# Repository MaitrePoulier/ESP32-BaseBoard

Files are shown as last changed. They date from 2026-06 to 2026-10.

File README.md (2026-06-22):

The goals of this BaseBoard:
* Support Bluetooth legacy for receiving audio from an external audio source
* Support 2x 18650 LiFePo4 cell that can be charged with the USB connector
* Low noise +/- 12.4V going to the mezzanine to powered Audio op-amp
* I2S port going to the mezz
* Support of the MHS 4.0 screen (ST7796S) with touch (XPT2046)
* can be placed inside an Pelican 1040 Micro Case

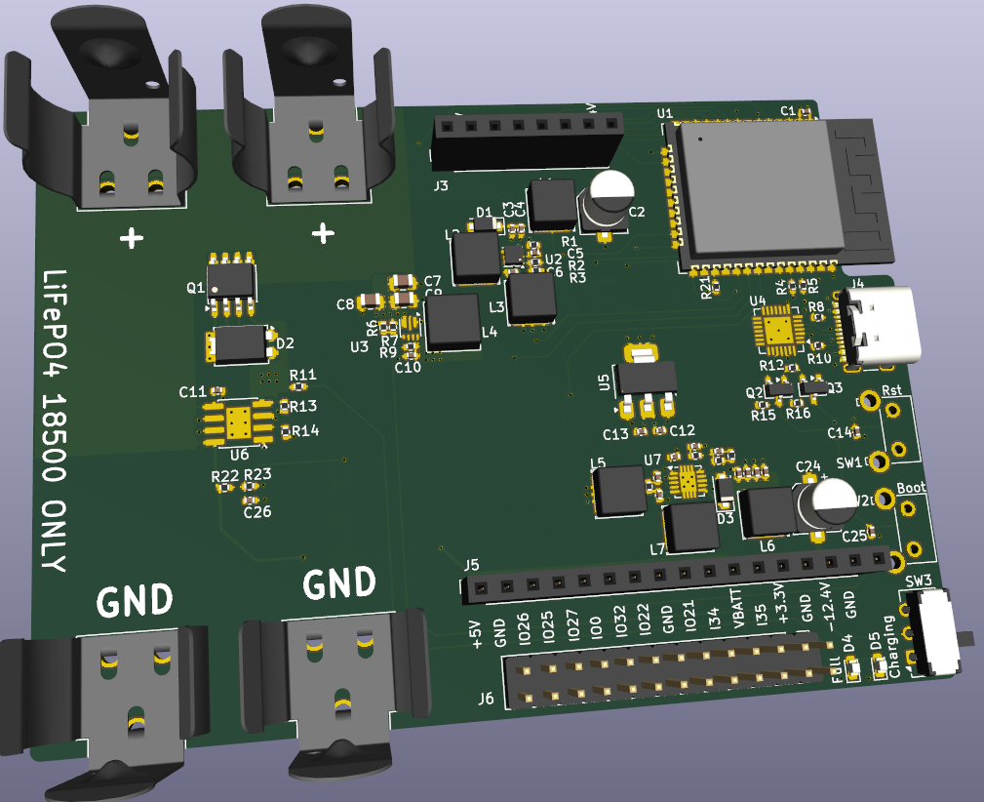
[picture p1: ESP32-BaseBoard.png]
ESP32 BaseBoard Picture


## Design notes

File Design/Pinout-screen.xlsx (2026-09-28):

 | ER-TFT043A1-1
 | Pin | Name | Type | Description
 | 1 | VLED- | Power | Backlight LED Cathode (Negative)
 | 2 | VLED+ | Power | Backlight LED Anode (Positive)
 | 3 | GND | Power | Ground
 | 4 | VDD | Power | Analog Power Supply (2.8V - 3.3V)
 | 5 | VDDIO | Power | Digital I/O Power Supply (1.65V - 3.3V)
 | 6 | RESET | Input | Global Reset Signal (Active Low)
 | 7 | CS | Input | SPI Chip Select (Active Low)
 | 8 | SCL | Input | SPI Clock Signal
 | 9 | SDA | I/O | SPI Data Input / Output
 | 10 | SDO | Output | SPI Data Output (MISO)
 | 11 | PCLK | Input | RGB Pixel Clock Signal
 | 12 | DE | Input | RGB Data Enable Signal
 | 13 | HSYNC | Input | RGB Horizontal Sync Signal
 | 14 | VSYNC | Input | RGB Vertical Sync Signal
 | 15 | D0 | Input | RGB Data Blue 0 (LSB)
 | 16 | D1 | Input | RGB Data Blue 1
 | 17 | D2 | Input | RGB Data Blue 2
 | 18 | D3 | Input | RGB Data Blue 3
 | 19 | D4 | Input | RGB Data Blue 4
 | 20 | D5 | Input | RGB Data Blue 5
 | 21 | D6 | Input | RGB Data Blue 6
 | 22 | D7 | Input | RGB Data Blue 7 (MSB)
 | 23 | D8 | Input | RGB Data Green 0 (LSB)
 | 24 | D9 | Input | RGB Data Green 1
 | 25 | D10 | Input | RGB Data Green 2
 | 26 | D11 | Input | RGB Data Green 3
 | 27 | D12 | Input | RGB Data Green 4
 | 28 | D13 | Input | RGB Data Green 5
 | 29 | D14 | Input | RGB Data Green 6
 | 30 | D15 | Input | RGB Data Green 7 (MSB)
 | 31 | D16 | Input | RGB Data Red 0 (LSB)
 | 32 | D17 | Input | RGB Data Red 1
 | 33 | D18 | Input | RGB Data Red 2
 | 34 | D19 | Input | RGB Data Red 3
 | 35 | D20 | Input | RGB Data Red 4
 | 36 | D21 | Input | RGB Data Red 5
 | 37 | D22 | Input | RGB Data Red 6
 | 38 | D23 | Input | RGB Data Red 7 (MSB)
 | 39 | GND | Power | Ground
 | 40 | NC | - | No Connection
 | 41 | NC | - | No Connection
 | 42 | NC | - | No Connection
 | 43 | NC | - | No Connection | 33
 | 44 | NC | - | No Connection
 | 45 | NC | - | No Connection
39 pins | 46 | NC | - | No Connection
 | 47 | NC | - | No Connection
 | 48 | NC | - | No Connection
 | 49 | NC | - | No Connection
 | 50 | GND | Power | Ground
 | Pin | Name | Type | Description
 | 1 | GND | Power | Ground
 | 2 | VCC | Power | Touch Controller Power Supply (2.8V - 3.3V)
 | 3 | SCL | Input | I2C Clock Signal
 | 4 | SDA | I/O | I2C Data Signal
 | 5 | INT | Output | Interrupt Output (Active Low, alerts MCU of touch event)
 | 6 | RESET | Input | Touch Controller Reset Signal (Active Low)

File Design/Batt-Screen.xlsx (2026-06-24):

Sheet: Height
 | Thickness of screen |  |  | 4.79
 | Thickness of Pcb |  |  | 1.6
total thickness of batt = 20mm | Header female thick | 13.55
 | PCB to PCB |  |  | 7.9
 | Middle pcb thick |  |  | 1.6
 | Header male |  | 2
 | PCB to PCB |  |  | 10.5
 | pin will be out of: | 4.45
 | Header male | 2 |  |  |  | For screen | pin are 6mm tall
 | Header plastic |  | 8.5 |  |  | For mid PCB
 | Thickness of Pcb |  |  | 1.6
 | Total: |  |  | 27.99 | mm

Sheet: Placement
https://www.lcdwiki.com/MHS-4.0inch_Display-B
 |  |  | C22466352
 | Donc
 | De bout en bout des cellule je vais avoir 72.4 mm
 | Ça devrait rentrer serré dans un pellican 1010
 | On va s’essayer avec un PCB de 68 mm de haut
 | En largeur, on va y aller avec le 95.5mm de l’écran
 | Les cellules vont bouffer 20mm de large.
 | Donc il reste 55.5mm pour le reste du design
 | https://www.lcdwiki.com/res/MHS4001-B/MHS-4.0inch_Display-B_User_Manual_EN.pdf
 | Screen position
 | x | 78.215
 | y | 4.855
 |  |  |  | https://www.lcdwiki.com/res/MHS4001-B/MHS4001-size.pdf

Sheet: Notes
Notes autour des filtres: | # page
condensateur COG/NPO | 2 | https://www.ti.com/lit/an/sbaa333a/sbaa333a.pdf
thin-film resistor. Les autres matériaux augmente le noise floor. | 2 | https://www.ti.com/lit/an/sbaa333a/sbaa333a.pdf
0.1% resistor pour la balance stéréo | 3 | https://www.ti.com/lit/an/sboa237/sboa237.pdf
For proper amplifier function, connect the package thermal pad to the most negative supply voltage (V–). | 9 | https://www.ti.com/lit/an/sboa237/sboa237.pdf
Goals:
SNR < 110 dB or 3.16uV for 1Vrms output | 2 | https://www.ti.com/lit/an/sboa237/sboa237.pdf
THD+N < -110dB | 2 | https://www.ti.com/lit/an/sboa237/sboa237.pdf
Isolation between channel > 100dB | 3 | https://www.ti.com/lit/an/sboa237/sboa237.pdf

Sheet: Parts Selection
 |  | THD+N | SNR | Power
DAC | PCM1794A | -108dB | 127 dB
First stage amplifier | 2x OPA1612 | -136.5 | 1.1 nV/√Hz at 1 kHz
Second stage amplifier | 2x OPA1622 | -119dB | 2.8 nV/√Hz at 1 kHz | 100mW into 32 Ohms
Pour le 5V du DAC | OPA1688
Resistor | RT0402BRC0710KL |  | 0.1% +/-15ppm/oC

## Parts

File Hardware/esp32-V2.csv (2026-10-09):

# | Qty | Value | Reference | PartNumber | LCSC | Description | DNP | Footprint | Datasheet
1 | 4 | Conn_01x01_Socket | J1,J2,J7,J8 | 54 | C2685232 | Connector, 18650 battery, single row, 01x01 |  | YV:BatteryClip_Keystone_54_D16-19mm
2 | 2 | 10k | R2,R6 | 0402WGF1002TCE | C25744 | Resistor, 10kΩ, 50V, 62.5mW, Thick Film, ±1%, ±100ppm/℃, 0402, -55℃~+155℃ |  | Resistor_SMD:R_0402_1005Metric
3 | 13 | 100k | R1,R3,R5,R7,R9,R10,R13,R19,R21,R25,R27,R28,R30 | 0402WGF1003TCE | C25741 | Res, 100kΩ, 50V, 62.5mW, Thick Film, ±1%, ±100ppm/℃, 0402, -55℃~+155℃ |  | Resistor_SMD:R_0402_1005Metric
4 | 4 | 100k | R20,R22,R23,R26 | 0402WGF1003TCE | C25741 | Res, 100kΩ, 50V, 62.5mW, Thick Film, ±1%, ±100ppm/℃, 0402, -55℃~+155℃ | DNP | Resistor_SMD:R_0402_1005Metric
5 | 1 | 1.54M | R15 | 0402WGF1544TCE | C407713 | Res, 1.54MΩ, 50V, 62.5mW, Thick Film, ±1%, ±100ppm/℃, 0402, -55℃~+155℃ |  | Resistor_SMD:R_0402_1005Metric
6 | 2 | 732k | R8,R16 | 0402WGF7323TCE | C27016 | Res, 732kΩ, 50V, 62.5mW, Thick Film, ±1%, ±100ppm/℃, 0402, -55℃~+155℃ |  | Resistor_SMD:R_0402_1005Metric
7 | 2 | 22uF | C2,C30 | 35SVPK22M | C454605 | Cap Polymer Aluminum, 22uF, 35V, 820mA@100kHz, ±20% SMD, 1000hrs@125℃ , D5xL5.9mm, -55℃~+125℃ |  | Capacitor_SMD:CP_Elec_5x5.9
8 | 2 | SW-000001 | SW2,SW3 | B3F-3105 | C397284 | Button, Push, 100,000 cycles, 2.6N, 24V, 50mA, 6mm x 6mm, Right Angle, Round Button, SPST-NO, DIP, Tactile Switches, -25℃~+70℃ |  | Button_Switch_THT:SW_SPST_Omron_B3F-315x_Angled
9 | 9 | BSDFN2C031U | D1,D2,D3,D4,D5,D6,D8,D12,D13 | BSDFN2C031U | C600818 | TVS, 0.65pF, 3.3V, 500nA, 50W@8/20us, 6.2V, 7A@8/20us, Bidirectional |  | PCM_JLCPCB:D_DFN1006-2L | https://xonstorage.z8.web.core.windows.net/pdf/bourne_bsdfn2c031u_xonjuly20_12_link.pdf
10 | 3 | BSMD1812-300-16V | F1,F2,F3 | BSMD1812-300-16V | C883162 | Fuse Resettable, 3A I Hold, 6A I Trip, 10 mOhms, -40℃~+85℃ |  | Fuse:Fuse_1812_4532Metric_Pad1.30x3.40mm_HandSolder | https://xonstorage.z8.web.core.windows.net/pdf/bhfuse_bsmd181230016v_apr22_xonlink.pdf
11 | 1 | 10pF | C16 | CC0402FRNPO9BN100 | C513681 | Cap C0G, 10pF, 50V, ±1%, 0402 |  | Capacitor_SMD:C_0402_1005Metric
12 | 9 | 4.7uF | C3,C18,C19,C20,C21,C24,C25,C26,C27 | CGA0402X5R475M250GT | C6119795 | Cap, 4.7uF, X5R, 25V, ±20%, 0402 |  | Capacitor_SMD:C_0402_1005Metric
13 | 3 | 22uF | C8,C9,C10 | CGA0805X7R226M100MT | C23692981 | Cap X7R, 22uF, ±20%, 10V, 0805 |  | Capacitor_SMD:C_0805_2012Metric
14 | 9 | 10uF | C1,C6,C7,C11,C12,C13,C14,C28,C29 | CL05A106MQ5NUNC | C15525 | Cap X5R, 10uF, 6.3V, ±20%, 0402 |  | Capacitor_SMD:C_0402_1005Metric
15 | 1 | CN3158 | U5 | CN3158 | C559032 | IC, LiFePO4 Battery Charger for Solar-Powered System, 1A, SOIC-8-1EP |  | YV:SOIC-8-1EP_3.9x4.9mm_P1.27mm_EP2.41x3.3mm_ThermalVias-0p3mm | http://www.consonance-elec.com/en/static/upload/file/20220425/1650867483177475.pdf
16 | 3 | 10uH | L2,L7,L8 | CR5020-100M | C520336 | Inductor, 10uH, Heat 1.5A, Sat 1.8A, 125mΩ, ±20%, SMD, 5x5mm |  | Inductor_SMD:L_Chilisin_BWVS00505030 | https://search.murata.co.jp/Ceramy/image/img/P02/JELF243A-0086.pdf
17 | 1 | DMP3015LSS-13 | Q1 | DMP3015LSS-13 | C508208 | MOSFET, P-MOS, -3.6A Id, -30V Vds, Ronon 0.09R, Micro8 |  | Package_SO:SOIC-8_3.9x4.9mm_P1.27mm
18 | 3 | Diode-DK24 | D7,D10,D11 | DSK24 | C22466352 | Diode Schottky, 2A, 40V, 500uA@40V, 50A, 550mV@2A, Standalone SOD-123FL, -55℃~+125℃ |  | Diode_SMD:D_SOD-123F
19 | 1 | 1.18k | R14 | ERA-2AEB1181X | C2088001 | Res, 1.18kΩ, 50V, 63mW, Thin Film Resistor, ±0.1%, ±25ppm/℃, 0402, -55℃~+155℃ |  | Resistor_SMD:R_0402_1005Metric
20 | 1 | ESP32-S31-WROOM-3-N16R16V | U3 | ESP32-S31-WROOM-3-N16R16V | C55371223 | IC, SOC, ESP32-S31, 54 GPIOs, 16MB Flash, 16MB PSRAM, PCB antenna, -40 to 85C |  | YV:ESP32-S31-WROOM-3 | https://documentation.espressif.com/esp32-s31-wroom-3_datasheet_en.html#pin_layout
21 | 1 | 150k | R12 | FRC0402F1503TS | C2909320 | Res, 150kΩ, 50V, 62.5mW, Thick Film, ±1%, ±100ppm/℃, 0402, -55℃~+155℃ |  | Resistor_SMD:R_0402_1005Metric
22 | 1 | 91k | R4 | FRC0402F9102TS | C2909393 | Res, 91kΩ, 50V, 62.5mW, Thick Film, ±1%, ±100ppm/℃, 0402, -55℃~+155℃ |  | Resistor_SMD:R_0402_1005Metric
23 | 1 | 10Ω | R18 | FRC0402F10R0TS | C2906862 | Res, 10Ω, 50V, 62.5mW, Thick Film, ±1%, ±100ppm/℃, 0402, -55℃~+155℃ |  | Resistor_SMD:R_0402_1005Metric
24 | 2 | 47Ω | R31,R32 | FRC0402F47R0TS | C2909362 | Res, 47Ω, 50V, 62.5mW, Thick Film, ±1%, ±100ppm/℃, 0402, -55℃~+155℃ |  | Resistor_SMD:R_0402_1005Metric
25 | 1 | Green, 3.2V | D15 | GL0603UG01 | C51933293 | LED Emerald Green 120° 20mA 3.2V 358mcd 510nm~531nm Top-mount Water Clear 0603 -40℃~+85℃ |  | LED_SMD:LED_0603_1608Metric
26 | 1 | Blue 2.9V | D14 | GL0603UB01 | C51933294 | LED Blue 120° 2.9V 20mA 460nm~469nm 72mcd Top-mount Water Clear 0603 -40℃~+85℃ |  | LED_SMD:LED_0603_1608Metric
27 | 2 | 1nF | C33,C34 | GRM1555C1H102GA01D | C2167623 | Cap,1nF, COG, 50V, ±2%, 0402 |  | Capacitor_SMD:C_0402_1005Metric
28 | 3 | 4.7nF | C4,C5,C17 | GRM1555C1H472JE01D | C1518204 | Cap C0G, 4.7nF, 50V, ±5% 0402 |  | Capacitor_SMD:C_0402_1005Metric
29 | 2 | 470nF | C31,C32 | GRM155R71C474KE01D | C471404 | Cap X7R, 470nF, 16V, ±10%, 0402 |  | Capacitor_SMD:C_0402_1005Metric
30 | 1 | HC-FPC-0.5-50P-FHH20 | J10 | HC-FPC-0.5-50P-FHH20 | C19273943 | Connector Zif, pitch 0.5mm, height 2mm, 50 Pos, Double-Sided Contacts, Top and Bottom Entry Flip-Top Gold Surface Mount, Right Angle, Surface Mount , -25℃~+85℃ |  | YV:HC-FPC-0.5-50P-FHH20
31 | 1 | SW_Push_DPDT | SW1 | JS202011AQN | C221662 | Switch, 300mA, 5000 cycles, 6V, DPDT, Slide Switches, -40℃~+85℃ |  | Button_Switch_THT:SW_CK_JS202011AQN_DPDT_Angled
32 | 1 | KH-FG0.5-H2.0-6PIN | J9 | KH-FG0.5-H2.0-6PIN | C709363 | Connector, Zif, 6 Pins, 0.5mm Pitch, Bottom Contact, -25℃~+85℃ |  | YV:ER-CON06HT-1
33 | 1 | LT1963AEST-3.3#TRPBF | U4 | LT1963AEST-3.3#TRPBF | C459918 | 1.5V, 1.5A, Low Noise, Fast Transient Response LDO Regulator, SOT-223 |  | Package_TO_SOT_SMD:SOT-223-3_TabPin2 | https://www.analog.com/media/en/technical-documentation/data-sheets/1963aff.pdf
34 | 1 | MT3608 | U7 | MT3608 | C84817 | IC, Step Up Converter, 1.2MHz 2A , 2-24V Vin, 28V Vout, 4A current limit, 1.2MHz, SOT23-6 |  | Package_TO_SOT_SMD:SOT-23-6 | https://www.olimex.com/Products/Breadboarding/BB-PWR-3608/resources/MT3608.pdf
35 | 1 | MAX17055ETB+T | U8 | MAX17055ETB+T | C2976422 | IC, LiFePO4 Battery Monitoring, 1x cell, 2.3V to 4.9V, 3.3V, 7uA, I2C, TDFN-10-EP, -40℃~+85℃ |  | YV:TDFN-10-EP-2x2p5-0p4mm | https://www.analog.com/media/en/technical-documentation/data-sheets/MAX17055.pdf
36 | 1 | MSD-4-A | J4 | MSD-4-A | C22367949 | Connector, Micro SD Card Socket with one card detection pin |  | YV:MSD4A | https://datasheet.lcsc.com/lcsc/2110151630_XKB-Connectivity-XKTF-015-N_C381082.pdf
37 | 4 | 2.9Ohms @ 1Mhz | L1,L3,L5,L6 | NFZ5BBW2R9LN10L | C711211 | Ferrite, 14mΩ, 2.9Ω@1MHz, 4A, ±30%, 2020 |  | Inductor_SMD:L_Chilisin_BWVS00505030
38 | 1 | Diode-PDS760 | D9 | PDS760 | C3018534 | Diode Schottky ,60V, 10A, 0.48Vf, TO-277B |  | Package_TO_SOT_SMD:TO-277B | https://lcsc.com/datasheet/lcsc_datasheet_2411271925_FUXINSEMI-PDS760_C3018534.pdf
39 | 1 | Conn_01x08_F_Header | J3 | PM254-1-08-Z-8.5 | C2897371 | Connector, Female Header, 8POS, 2.54mm, SINGLE ROW, TH |  | Connector_PinSocket_2.54mm:PinSocket_1x08_P2.54mm_Vertical
40 | 1 | PM254-1-17-Z-8.5 | J5 | PM254-1-17-Z-8.5 | C2897380 | Connector, Female Header, 17POS, 2.54mm, SINGLE ROW, TH |  | Connector_PinSocket_2.54mm:PinSocket_1x17_P2.54mm_Vertical
41 | 1 | 10mΩ | R24 | RLM12FTCMR010 | C188070 | Res, 10mΩ, 1W, ±1%, ±50ppm/℃, 1206, -55℃~+170℃ |  | Resistor_SMD:R_1206_3216Metric
42 | 1 | 31.6k | R17 | RT0402BRD0731K6L | C852720 | Res, 31.6kΩ, 50V, 62.5mW, Thin Film, Resistor ±0.1%, ±25ppm/℃, 0402, -55℃~+155℃ |  | Resistor_SMD:R_0402_1005Metric
43 | 1 | 357Ω | R11 | RT0402BRD07357RL | C852736 | Res, 357Ω, 100mW, Thin Film, ±0.1%, ±25ppm/℃, 0402, -55℃~+155℃ |  | Resistor_SMD:R_0402_1005Metric
44 | 2 | 5.1k | R29,R33 | SC0402J5101F2ANRH | C5356293 | Res, 5.1kΩ, 50V, 62.5mW, Thick Film, ±100ppm/℃, ±5%, 0402, -55℃~+155℃ |  | Resistor_SMD:R_0402_1005Metric
45 | 2 | 220nF | C15,C23 | TCC0402X7R224K250AT | C915854 | Cap X7R, 220nF, 25V, ±10%, 0402 |  | Capacitor_SMD:C_0402_1005Metric
46 | 1 | IC-TPS61022 | U2 | TPS61022RWUR | C915088 | IC, Boost Converter, 8A, 0.5-5.5 V input, 2.2-5.5V output, VQFN-7 |  | Package_DFN_QFN:Texas_RWU0007A_VQFN-7_2x2mm_P0.5mm | https://www.ti.com/lit/ds/symlink/tps61022.pdf
47 | 1 | TPS61170DRVR | U1 | TPS61170DRVR | C15163 | IC, Buck-Boost, Flyback, 3V-18V to 3V-38V, 1 Output, 960mA |  | Package_SON:WSON-6-1EP_2x2mm_P0.65mm_EP1x1.6mm | https://www.ti.com/lit/gpn/tps61170
48 | 1 | TPS63700 | U6 | TPS63700DRDR | C54792 | IC, Buck-Boost, Negative Adjustable, -15V to -2V 1 Output, 360mA, 10-VFDFN, -40C to 85C |  | Package_SON:Texas_S-PWSON-N10_ThermalVias | https://www.ti.com/lit/gpn/tps63700
49 | 1 | USB_C_Receptacle-16p | J6 | USB4105-GF-A-060 | C3025063 | Connector, USB Type-C Female, USB 2.0-only, 16P Type-C |  | Connector_USB:USB_C_Receptacle_GCT_USB4105-xx-A_16P_TopMnt_Horizontal | https://www.usb.org/sites/default/files/documents/usb_type-c.zip
50 | 1 | 1uH | L4 | XFL5030-102MEC | C18208905 | Inductor, 1uH, 13A, 4.2mΩ, 6.2A, ±20%, SMD,5.5x5.3mm |  | Inductor_SMD:L_Coilcraft_XAL5030-XXX | https://www.coilcraft.com/getmedia/f01e4ccd-6be9-43eb-bb01-c23b4deeb2c5/xfl5030.pdf

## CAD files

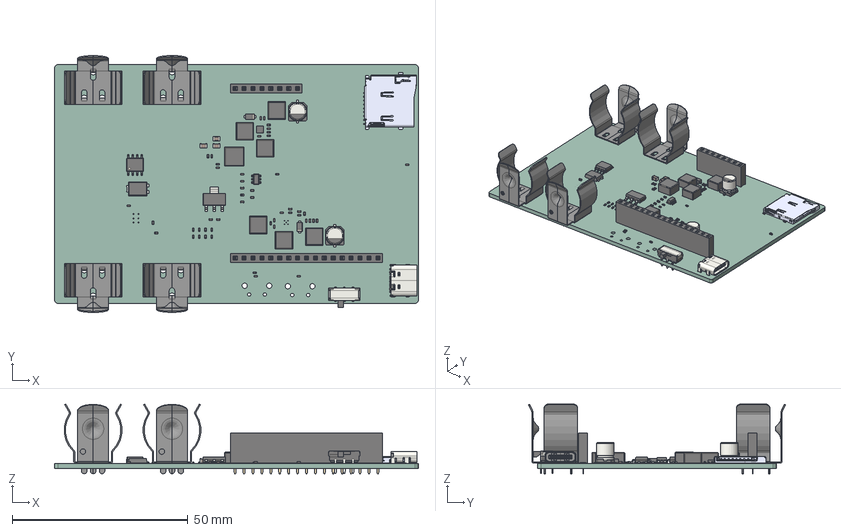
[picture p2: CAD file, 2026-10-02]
Hardware/esp32-V2.step
103.7 x 73.2 x 19.9 mm
C_0805_2012Metric x 3
C_0402_1005Metric x 25
SW_CuK_JS202011AQN_DPDT_Angled
R_0402_1005Metric x 24
TO_277B_sp
SOIC-8_3.9x4.9mm_P1.27mm
L_Coilcraft_XAL5030-XXX
BatteryClip_Keystone_54_16-19mm x 4
CP_Elec_5x59 x 2
L_Chilisin_BWVS00505030 x 6
PinSocket_1x17_P2.54mm_Vertical
WSON_6_1EP_2x2mm_P065mm_EP1x16mm
PinSocket_1x08_P2.54mm_Vertical
USB_C_Receptacle_16P_TopMnt_Horizontal_GCT_USB4105-xx-A
D_SOD_123F x 2
CUI_DEVICES_MSD-4-A
SOT-223
SOT-23-6
esp32-V2-unsaved-export-UWcyw0_PCB

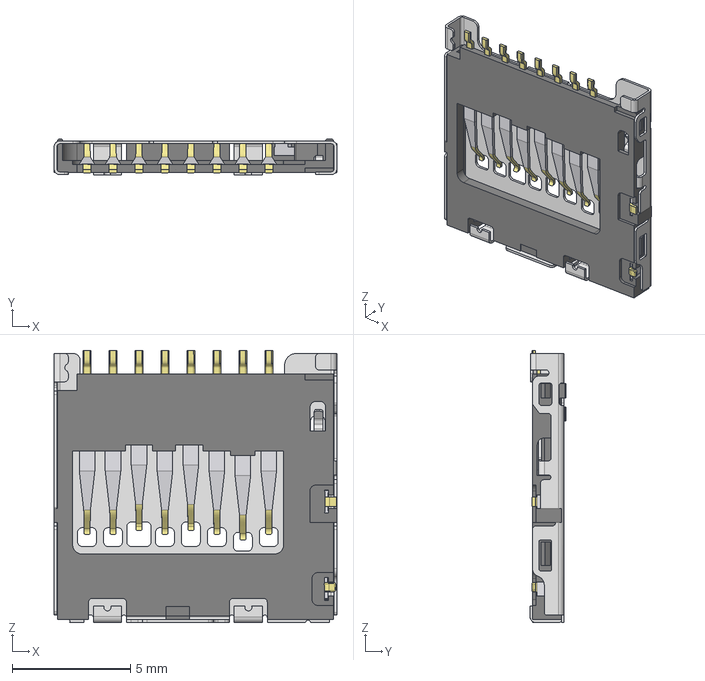
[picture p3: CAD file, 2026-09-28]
Hardware/1040310811.stp
12.0 x 1.53 x 11.5 mm

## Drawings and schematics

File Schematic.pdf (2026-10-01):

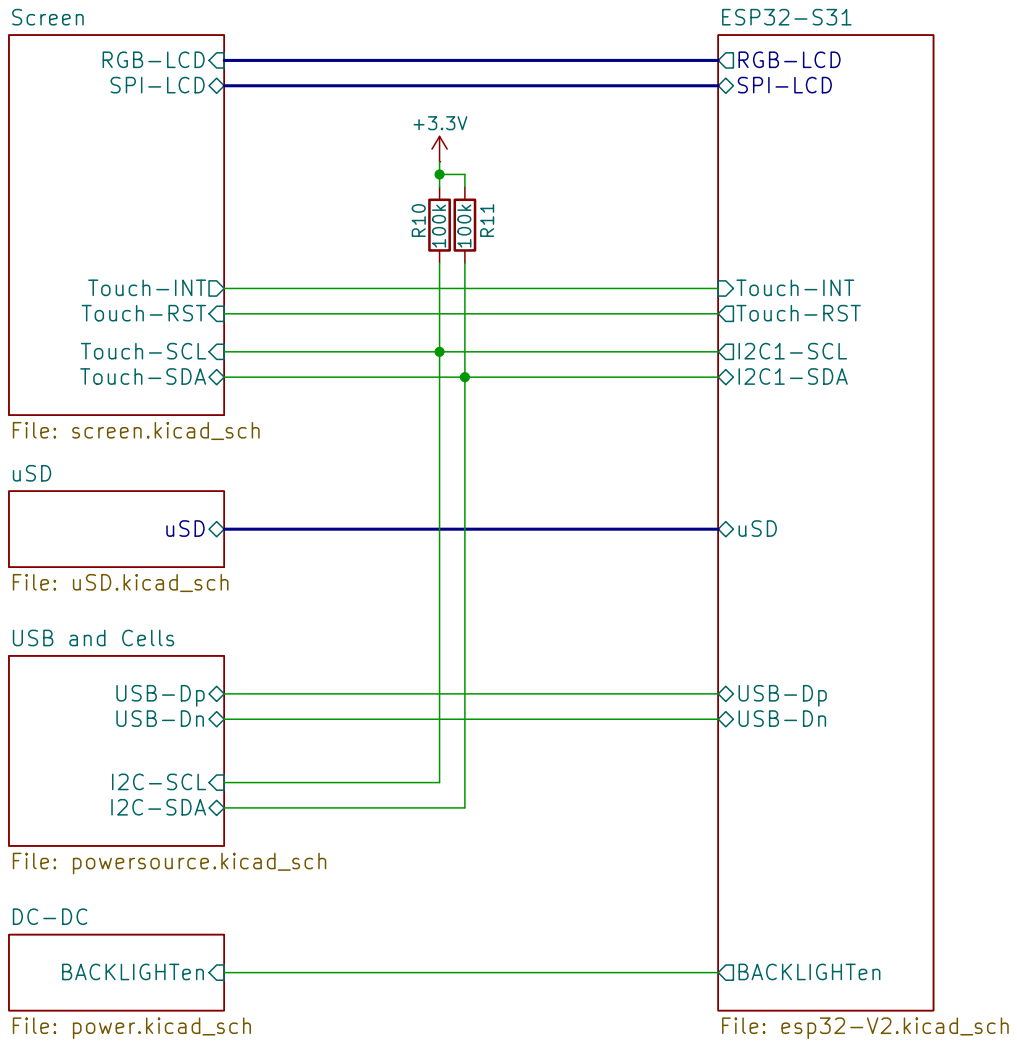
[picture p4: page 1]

by Yannick Vallée, ing.
Motion Composites
Sheet: /
File: top.kicad_sch
Title: Strain Gauge Data Logger

Size: A4 | Rev: 1
KiCad E.D.A. 10.0.6 | Id: 1/6

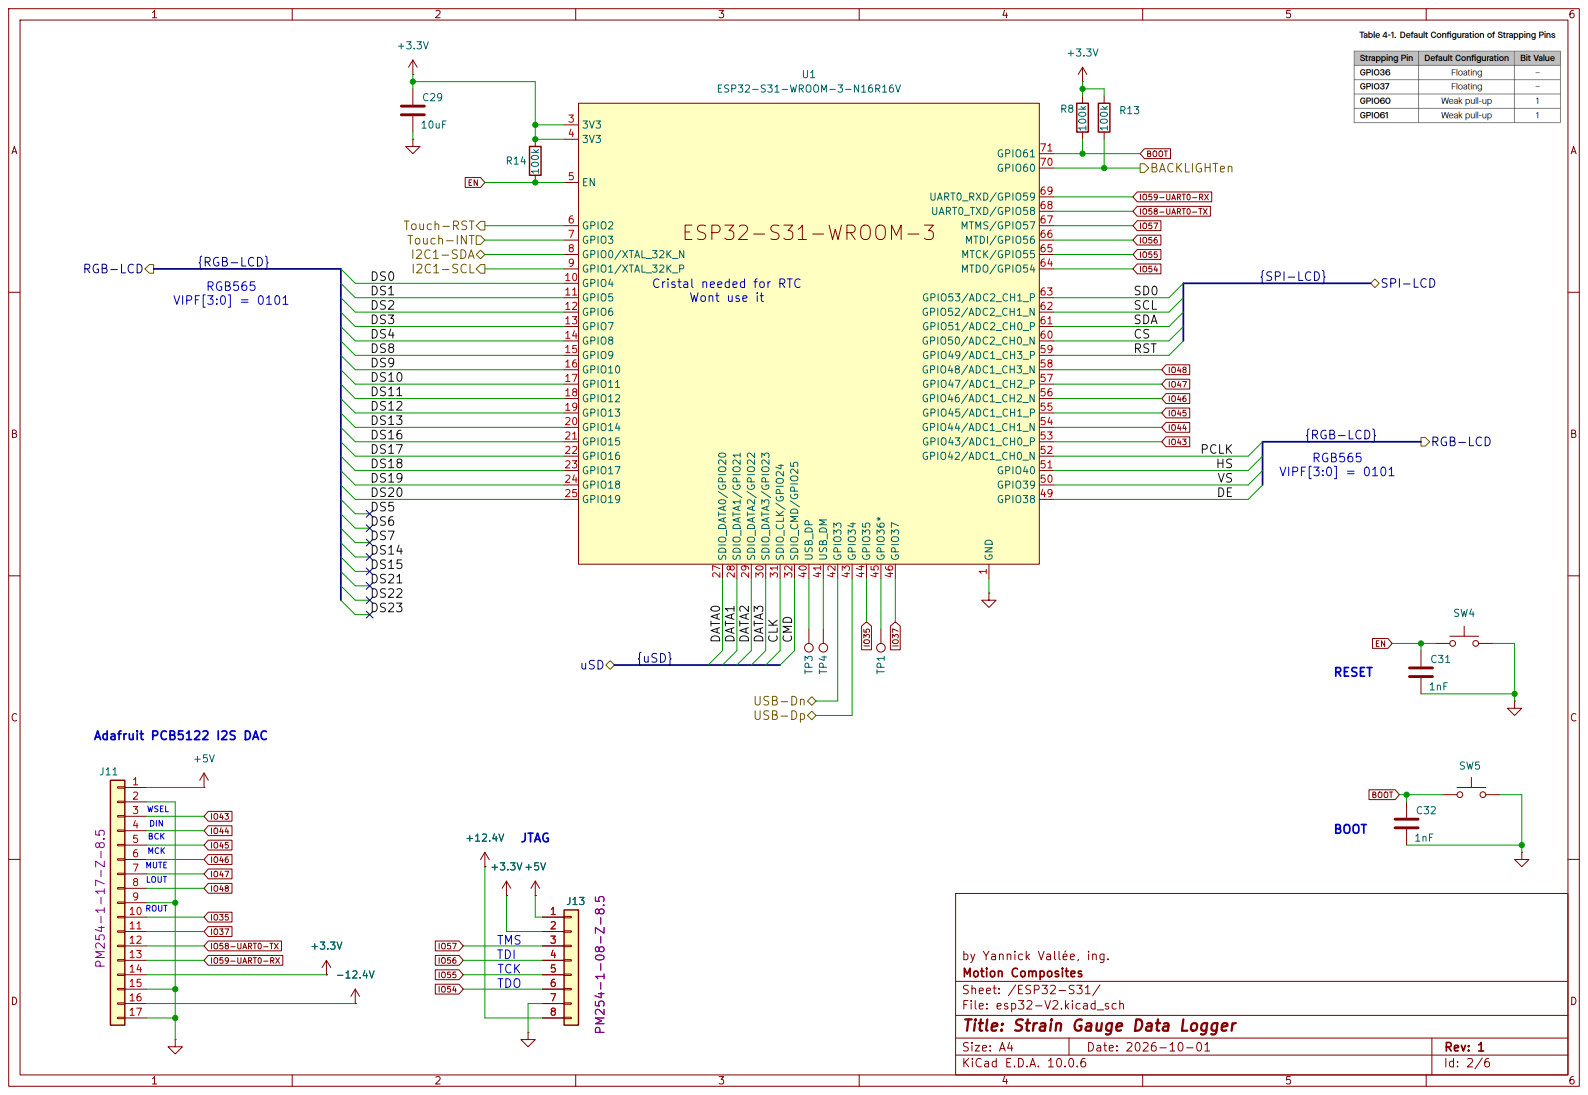
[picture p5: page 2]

Cristal needed for RTC

Motion Composites
Sheet: /ESP32-S31/
File: esp32-V2.kicad_sch
Title: Strain Gauge Data Logger

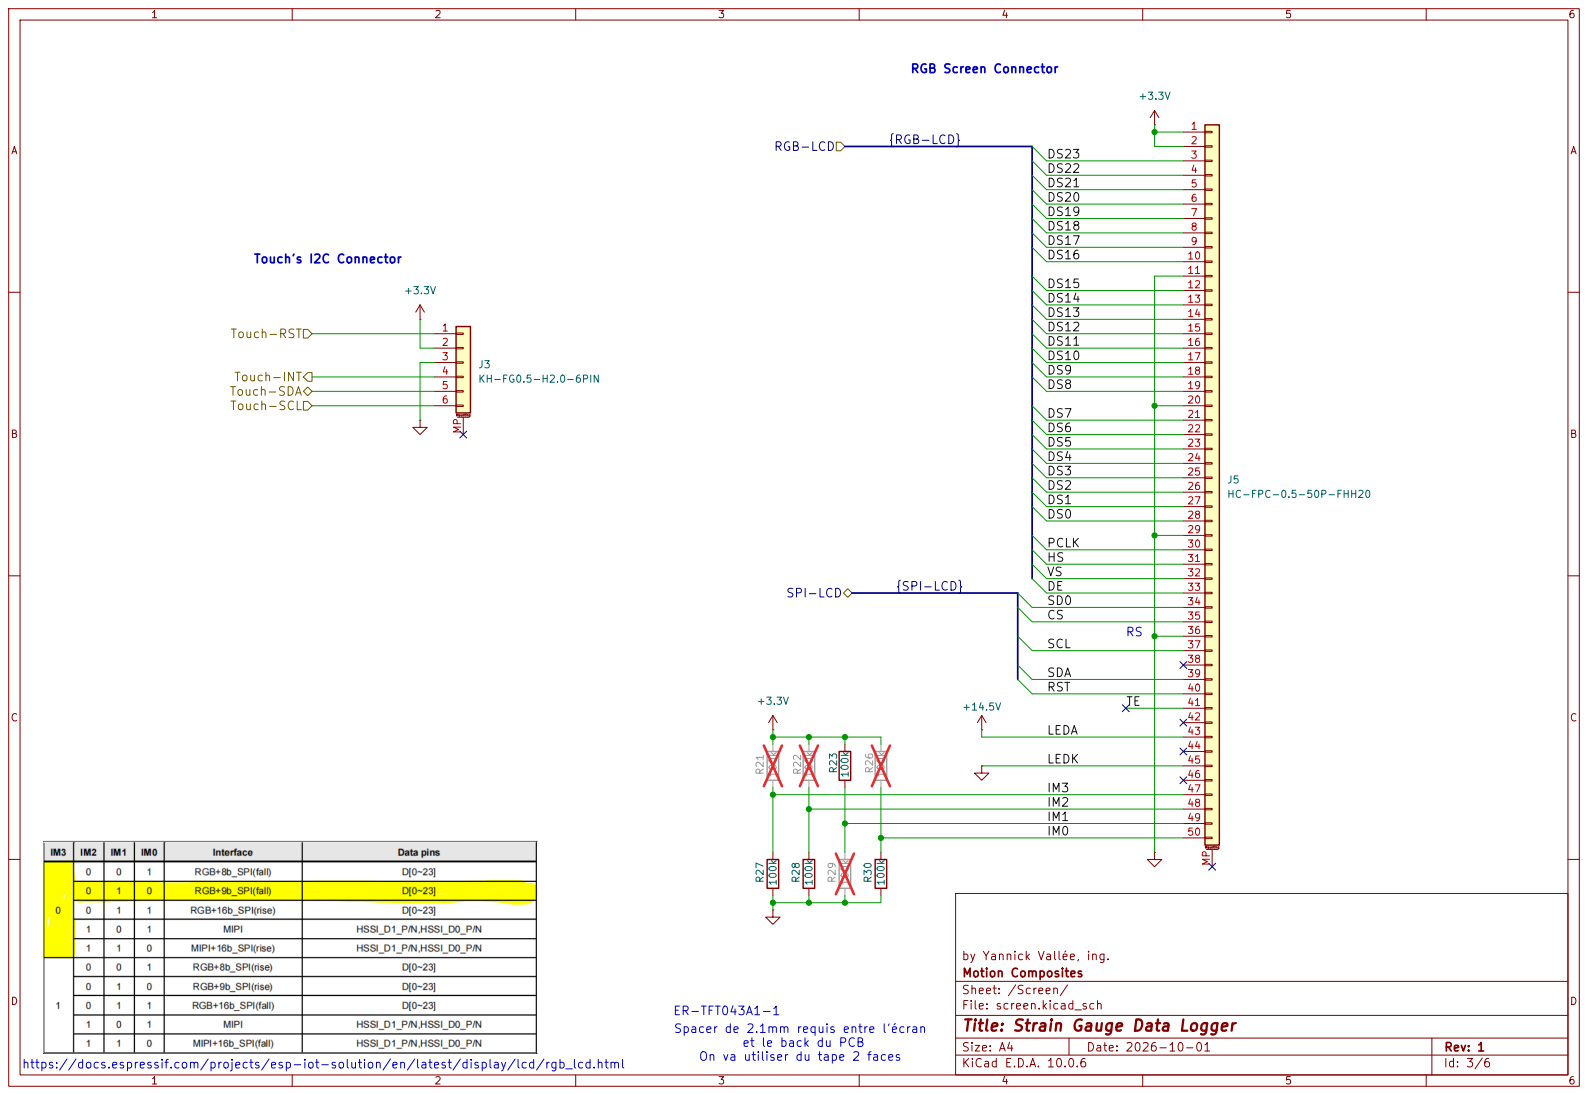
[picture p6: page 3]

IM2 | 48
IM1 | 49
IM0

Motion Composites
Sheet: /Screen/
File: screen.kicad_sch
Title: Strain Gauge Data Logger

ER-TFT043A1-1
Spacer de 2.1mm requis entre l'écran

et le back du PCB

https://docs.espressif.com/projects/esp-iot-solution/en/latest/display/lcd/rgb_lcd.html

On va utiliser du tape 2 faces

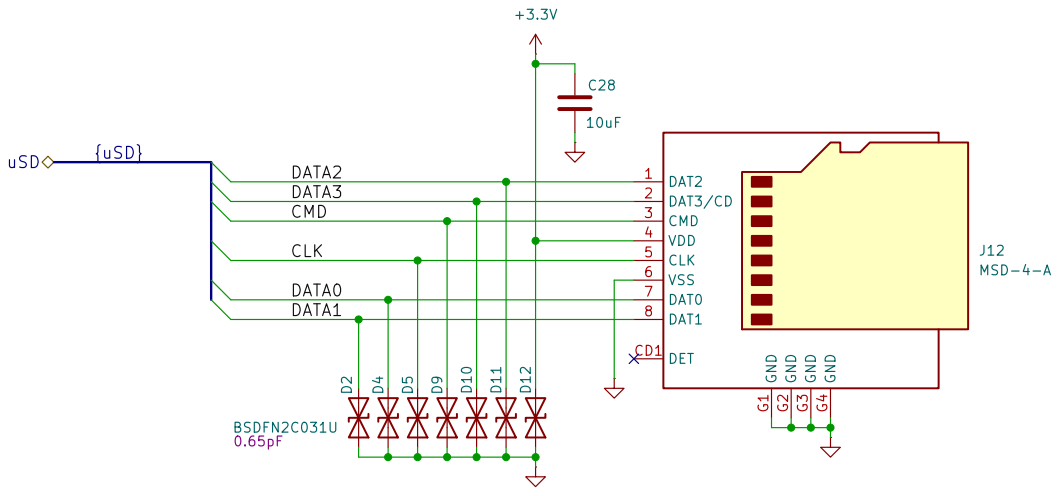
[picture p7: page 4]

by Yannick Vallée, ing. D2 BSDFN2C031U

Motion Composites
Sheet: /uSD/
File: uSD.kicad_sch
Title: Strain Gauge Data Logger

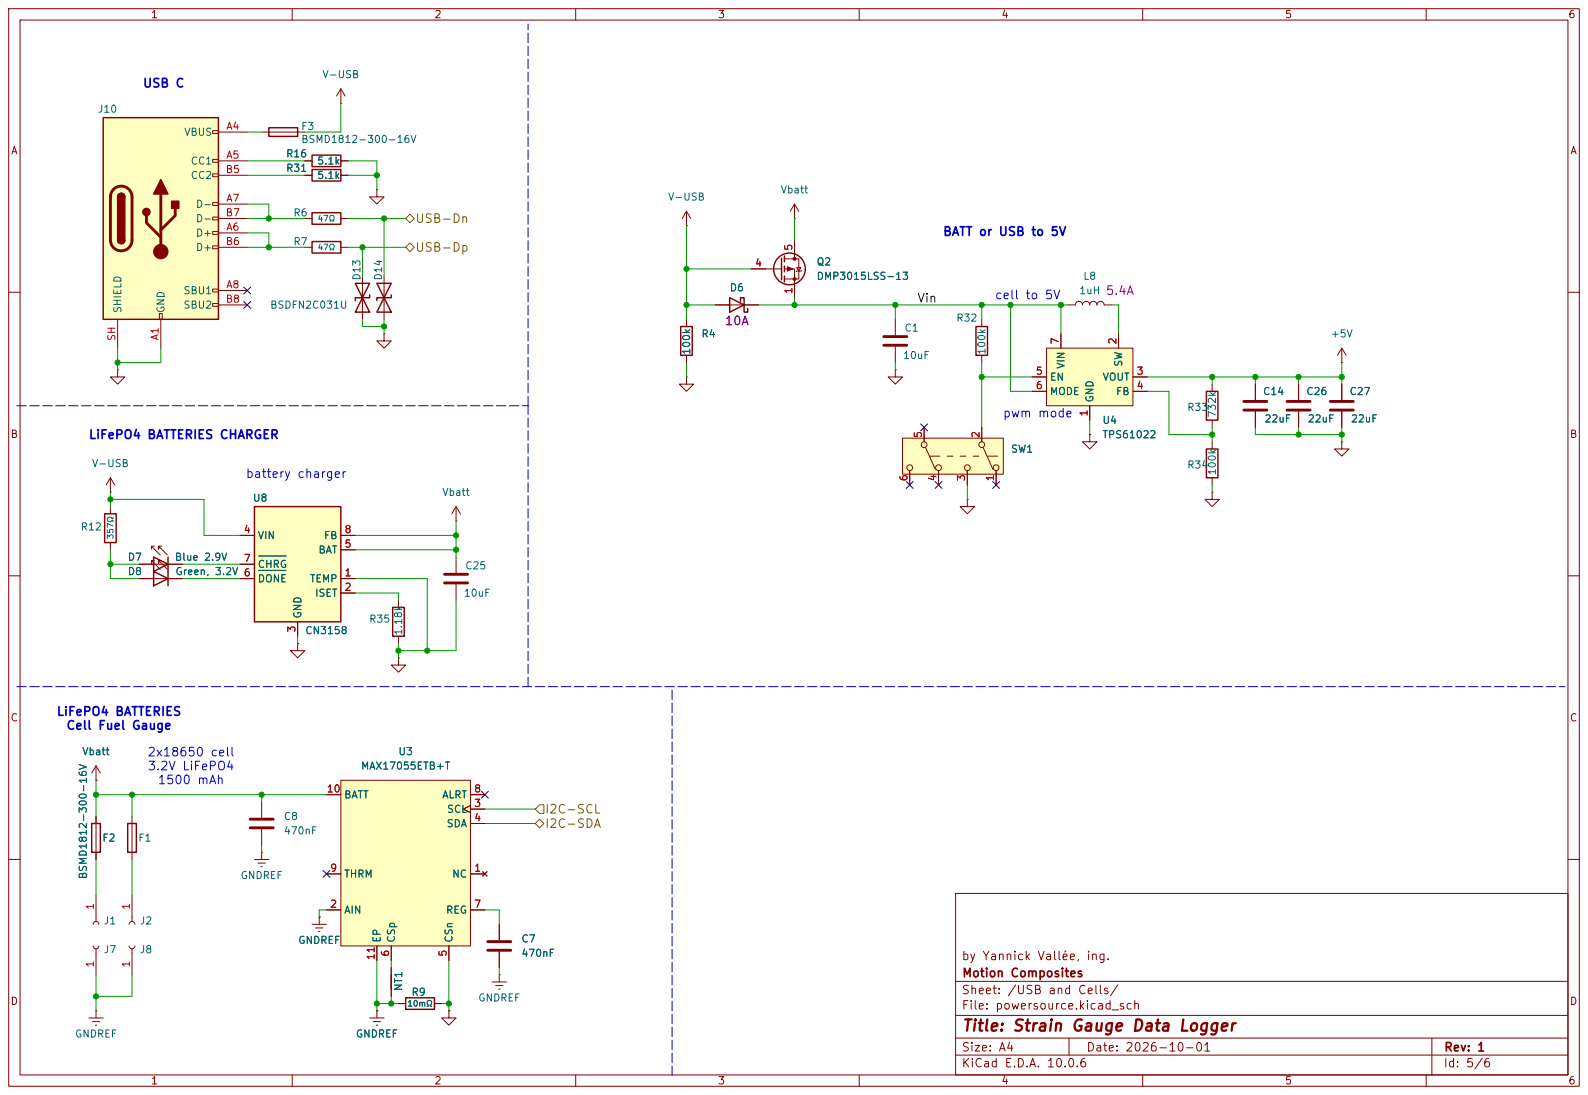
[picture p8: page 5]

BATT or USB to 5V

by Yannick Vallée, ing. 1

Motion Composites
Sheet: /USB and Cells/
File: powersource.kicad_sch
Title: Strain Gauge Data Logger

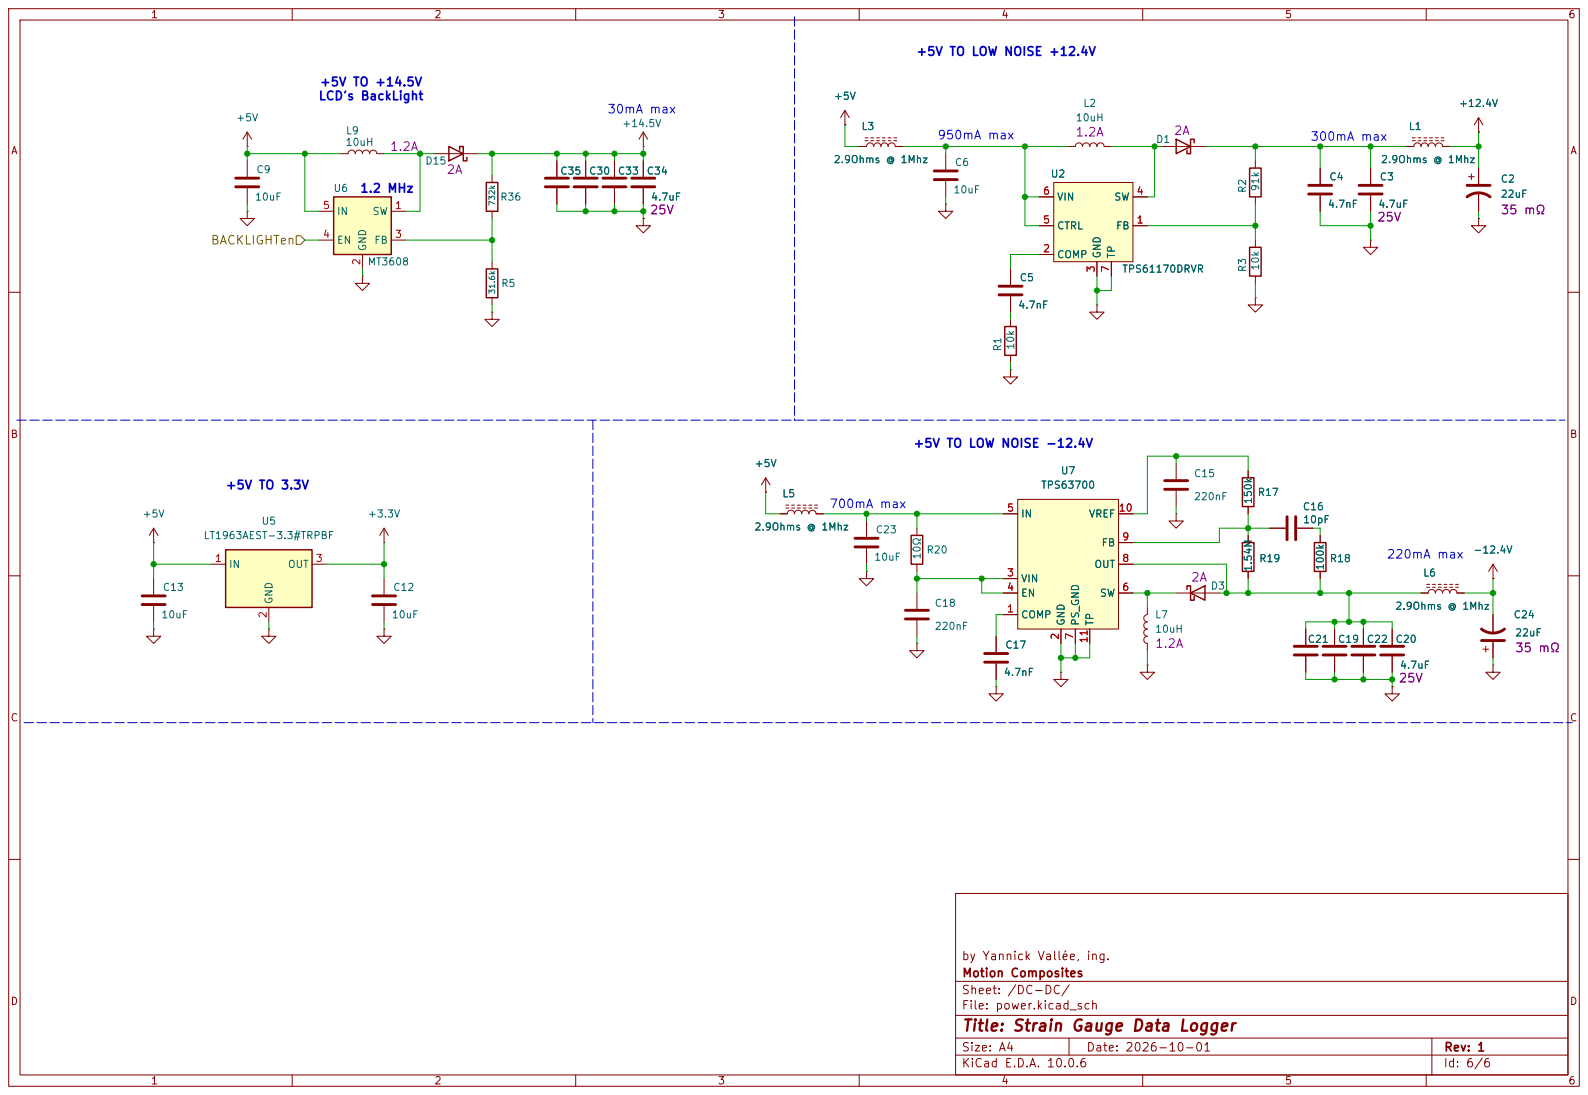
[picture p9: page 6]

by Yannick Vallée, ing.
Motion Composites
Sheet: /DC-DC/
File: power.kicad_sch
Title: Strain Gauge Data Logger

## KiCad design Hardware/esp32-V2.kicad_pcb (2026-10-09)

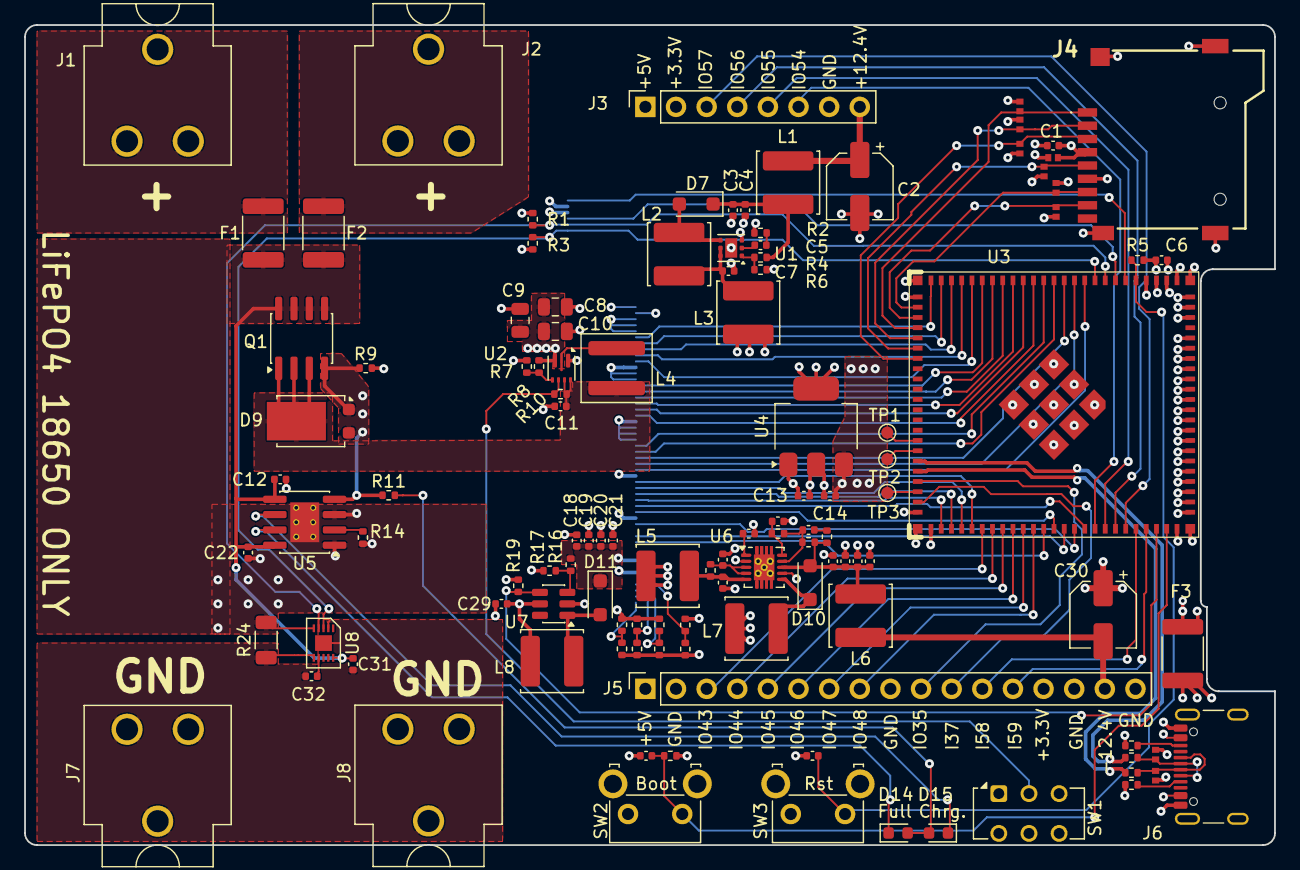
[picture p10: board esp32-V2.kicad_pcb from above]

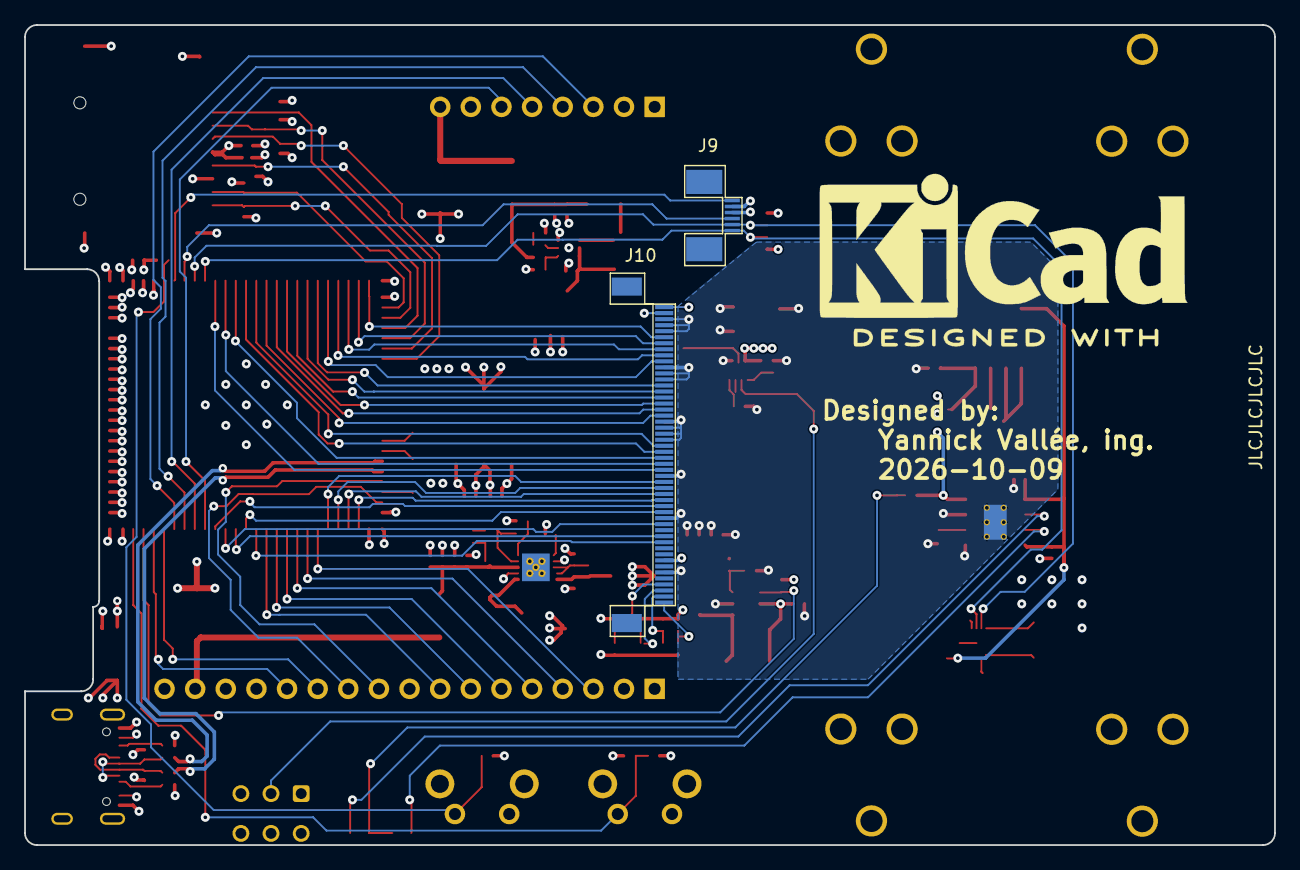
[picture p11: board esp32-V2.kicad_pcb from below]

Board: 4 copper layers, 103.7 x 68.0 mm, 119 parts (2 on the bottom side), 103 nets.

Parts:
C1, C6, C7, C11, C12, C13, C14, C22, C28, C29: 10uF; C_0402_1005Metric
C2, C30: 22uF; CP_Elec_5x5.9
C3, C18, C19, C20, C21, C24, C25, C26, C27: 4.7uF; C_0402_1005Metric
C4, C5, C17: 4.7nF; C_0402_1005Metric
C8, C9, C10: 22uF; C_0805_2012Metric
C15, C23: 220nF; C_0402_1005Metric
C16: 10pF; C_0402_1005Metric
C31, C32: 470nF; C_0402_1005Metric
C33, C34: 1nF; C_0402_1005Metric
D1, D2, D3, D4, D5, D6, D8, D12, D13: BSDFN2C031U; D_DFN1006-2L
D7, D10, D11: Diode-DK24; D_SOD-123F
D9: Diode-PDS760; TO-277B
D14: Blue 2.9V; LED_0603_1608Metric
D15: Green, 3.2V; LED_0603_1608Metric
F1, F2, F3: BSMD1812-300-16V; Fuse_1812_4532Metric_Pad1.30x3.40mm_HandSolder
J1, J2, J7, J8: Conn_01x01_Socket; BatteryClip_Keystone_54_D16-19mm
J3: Conn_01x08_F_Header; PinSocket_1x08_P2.54mm_Vertical
J4: MSD-4-A; MSD4A
J5: PM254-1-17-Z-8.5; PinSocket_1x17_P2.54mm_Vertical
J6: USB_C_Receptacle-16p; USB_C_Receptacle_GCT_USB4105-xx-A_16P_TopMnt_Horizontal
J9: KH-FG0.5-H2.0-6PIN; ER-CON06HT-1
J10: HC-FPC-0.5-50P-FHH20
L1, L3, L5, L6: 2.9Ohms @ 1Mhz; L_Chilisin_BWVS00505030
L2, L7, L8: 10uH; L_Chilisin_BWVS00505030
L4: 1uH; L_Coilcraft_XAL5030-XXX
NT1: NetTie_2; NetTie-2_SMD_Pad0.16mm
Q1: DMP3015LSS-13; SOIC-8_3.9x4.9mm_P1.27mm
R1, R3, R5, R7, R9, R10, R13, R19, R20, R21, R22, R23, R25, R26, R27, R28, R30: 100k; R_0402_1005Metric
R2, R6: 10k; R_0402_1005Metric
R4: 91k; R_0402_1005Metric
R8, R16: 732k; R_0402_1005Metric
R11: 357Ω; R_0402_1005Metric
R12: 150k; R_0402_1005Metric
R14: 1.18k; R_0402_1005Metric
R15: 1.54M; R_0402_1005Metric
R17: 31.6k; R_0402_1005Metric
R18: 10Ω; R_0402_1005Metric
R24: 10mΩ; R_1206_3216Metric
R29, R33: 5.1k; R_0402_1005Metric
R31, R32: 47Ω; R_0402_1005Metric
SW1: SW_Push_DPDT; SW_CK_JS202011AQN_DPDT_Angled
SW2, SW3: SW-000001; SW_SPST_Omron_B3F-315x_Angled
TP1, TP2, TP3: TestPoint; TestPoint_Pad_D1.0mm
U1: TPS61170DRVR; WSON-6-1EP_2x2mm_P0.65mm_EP1x1.6mm
U2: IC-TPS61022; Texas_RWU0007A_VQFN-7_2x2mm_P0.5mm
U3: ESP32-S31-WROOM-3-N16R16V; ESP32-S31-WROOM-3
U4: LT1963AEST-3.3#TRPBF; SOT-223-3_TabPin2
U5: CN3158; SOIC-8-1EP_3.9x4.9mm_P1.27mm_EP2.41x3.3mm_ThermalVias-0p3mm
U6: TPS63700; Texas_S-PWSON-N10_ThermalVias
U7: MT3608; SOT-23-6
U8: MAX17055ETB+T; TDFN-10-EP-2x2p5-0p4mm

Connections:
+3.3V: C1.1, C6.1, C14.1, D4.2 (A2), J3.2, J4.4 (VDD), J5.14, J9.2, J10.1, J10.2, R1.1, R3.1, R5.1, R19.1, R20.2, R21.2, R22.2, R23.2, R30.1, U3.3 (3V3), U3.4 (3V3), U4.3 (OUT)
+5V: C8.1, C9.1, C10.1, C13.1, C29.1, J3.1, J5.1, L3.1, L5.1, L8.1, R8.2, U2.3 (VOUT), U4.1 (IN), U7.5 (IN)
+12.4V: C2.1, J3.8, L1.2
+14.5V: C18.1, C19.1, C20.1, C21.1, D11.1 (K), J10.43, R16.2
-12.4V: C30.2, J5.16, L6.2
/DC-DC/BACKLIGHTen: R19.2, U3.70 (GPIO60), U7.4 (EN)
/ESP32-S31/CLK: D5.2 (A2), J4.5 (CLK), U3.31 (SDIO_CLK/GPIO24)
/ESP32-S31/CMD: D3.2 (A2), J4.3 (CMD), U3.32 (SDIO_CMD/GPIO25)
/ESP32-S31/CS: J10.35, U3.60 (GPIO50/ADC2_CH0_N)
/ESP32-S31/DATA0: D6.2 (A2), J4.7 (DAT0), U3.27 (SDIO_DATA0/GPIO20)
/ESP32-S31/DATA1: D8.2 (A2), J4.8 (DAT1), U3.28 (SDIO_DATA1/GPIO21)
/ESP32-S31/DATA2: D1.2 (A2), J4.1 (DAT2), U3.29 (SDIO_DATA2/GPIO22)
/ESP32-S31/DATA3: D2.2 (A2), J4.2 (DAT3/CD), U3.30 (SDIO_DATA3/GPIO23)
/ESP32-S31/DE: J10.33, U3.49 (GPIO38)
/ESP32-S31/DS0: J10.28, U3.10 (GPIO4)
/ESP32-S31/DS1: J10.27, U3.11 (GPIO5)
/ESP32-S31/DS2: J10.26, U3.12 (GPIO6)
/ESP32-S31/DS3: J10.25, U3.13 (GPIO7)
/ESP32-S31/DS4: J10.24, U3.14 (GPIO8)
/ESP32-S31/DS8: J10.19, U3.15 (GPIO9)
/ESP32-S31/DS9: J10.18, U3.16 (GPIO10)
/ESP32-S31/DS10: J10.17, U3.17 (GPIO11)
/ESP32-S31/DS11: J10.16, U3.18 (GPIO12)
/ESP32-S31/DS12: J10.15, U3.19 (GPIO13)
/ESP32-S31/DS13: J10.14, U3.20 (GPIO14)
/ESP32-S31/DS16: J10.10, U3.21 (GPIO15)
/ESP32-S31/DS17: J10.9, U3.22 (GPIO16)
/ESP32-S31/DS18: J10.8, U3.23 (GPIO17)
/ESP32-S31/DS19: J10.7, U3.24 (GPIO18)
/ESP32-S31/DS20: J10.6, U3.25 (GPIO19)
/ESP32-S31/HS: J10.31, U3.51 (GPIO40)
/ESP32-S31/I2C1-SCL: J9.6, R3.2, U3.9 (GPIO1/XTAL_32K_P), U8.3 (SCL)
/ESP32-S31/I2C1-SDA: J9.5, R1.2, U3.8 (GPIO0/XTAL_32K_N), U8.4 (SDA)
/ESP32-S31/PCLK: J10.30, U3.52 (GPIO42/ADC1_CH0_N)
/ESP32-S31/RST: J10.40, U3.59 (GPIO49/ADC1_CH3_P)
/ESP32-S31/SCL: J10.37, U3.62 (GPIO52/ADC2_CH1_N)
/ESP32-S31/SD0: J10.34, U3.63 (GPIO53/ADC2_CH1_P)
/ESP32-S31/SDA: J10.39, U3.61 (GPIO51/ADC2_CH0_P)
/ESP32-S31/Touch-INT: J9.4, U3.7 (GPIO3)
/ESP32-S31/Touch-RST: J9.1, U3.6 (GPIO2)
/ESP32-S31/USB_D+: R32.2, U3.43 (GPIO34)
/ESP32-S31/USB_D-: R31.2, U3.42 (GPIO33)
/ESP32-S31/VS: J10.32, U3.50 (GPIO39)
/Screen/IM0: J10.50, R20.1, R25.2
/Screen/IM1: J10.49, R21.1, R26.2
/Screen/IM2: J10.48, R22.1, R27.2
/Screen/IM3: J10.47, R23.1, R28.2
/USB and Cells/D+: D13.2 (A2), J6.A6 (D+), J6.B6 (D+), R32.1
/USB and Cells/D-: D12.2 (A2), J6.A7 (D-), J6.B7 (D-), R31.1
/USB and Cells/Vin: C11.1, D9.3 (K), L4.1, Q1.1 (S), Q1.2 (S), Q1.3 (S), R10.1, U2.6 (MODE), U2.7 (VIN)
BOOT: C33.1, R30.2, SW2.1, U3.71 (GPIO61)
EN: C34.1, R5.2, SW3.1, U3.5 (EN)
GND: C1.2, C2.2, C3.2, C4.2, C6.2, C7.2, C8.2, C9.2, C10.2, C11.2, C12.2, C13.2, C14.2, C15.1, C17.2, C18.2, C19.2, C20.2, C21.2, C22.2, C23.1, C24.2, C25.2, C26.2, C27.2, C28.2, C29.2, C30.1, C33.2, C34.2, D1.1 (A1), D2.1 (A1), D3.1 (A1), D4.1 (A1), D5.1 (A1), D6.1 (A1), D8.1 (A1), D12.1 (A1), D13.1 (A1), J3.7, J4.6 (VSS), J4.G1 (GND), J4.G2 (GND), J4.G3 (GND), J4.G4 (GND), J5.2, J5.9, J5.15, J5.17, J6.A1 (GND), J6.A12 (GND), J6.B1 (GND), J6.B12 (GND), J6.SH (SHIELD), J9.3, J10.3, J10.4, J10.5, J10.11, J10.12, J10.13, J10.20, J10.21, J10.22, J10.23, J10.29, J10.36, J10.45, L7.1, R2.1, R6.1, R7.1, R9.2, R14.1, R17.2, R24.2, R25.1, R26.1, R27.1, R28.1, R29.2, R33.2, SW1.3 (C), SW2.2, SW3.2, U1.3 (GND), U1.7 (TP), U2.1 (GND), U3.1 (GND), U3.2 (GND), U3.26 (GND), U3.47 (GND), U3.48 (GND), U3.72 (GND), U3.73 (GND), U3.74 (GND), U3.75 (GND), U3.76 (GND), U3.77 (GND), U3.78 (GND), U3.79 (GND), U3.80 (GND), U3.81 (GND), U3.82 (GND), U3.83 (GND), U3.84 (GND), U3.85 (GND), U3.86 (GND), U3.87 (GND), U3.88 (GND), U3.89 (GND), U3.90 (GND), U3.92 (GND), U3.93 (GND), U3.94 (GND), U3.95 (GND), U3.96 (GND), U3.97 (GND), U3.98 (GND), U3.99 (GND), U4.2 (GND), U5.1 (TEMP), U5.3 (GND), U5.9 (GND), U6.2 (GND), U6.7 (PS_GND), U6.11 (TP), U7.2 (GND), U8.5 (CSn)
GNDREF: C31.1, C32.1, J7.1 (Pin_1_1), J8.1 (Pin_1_1), NT1.1, R24.1, U8.2 (AIN), U8.11 (EP)
IO35: J5.10, U3.44 (GPIO35)
IO37: J5.11, U3.46 (GPIO37)
IO43: J5.3, U3.53 (GPIO43/ADC1_CH0_P)
IO44: J5.4, U3.54 (GPIO44/ADC1_CH1_N)
IO45: J5.5, U3.55 (GPIO45/ADC1_CH1_P)
IO46: J5.6, U3.56 (GPIO46/ADC1_CH2_N)
IO47: J5.7, U3.57 (GPIO47/ADC1_CH2_P)
IO48: J5.8, U3.58 (GPIO48/ADC1_CH3_N)
IO54: J3.6, U3.64 (MTDO/GPIO54)
IO55: J3.5, U3.65 (MTCK/GPIO55)
IO56: J3.4, U3.66 (MTDI/GPIO56)
IO57: J3.3, U3.67 (MTMS/GPIO57)
IO58-UART0-TX: J5.12, U3.68 (UART0_TXD/GPIO58)
IO59-UART0-RX: J5.13, U3.69 (UART0_RXD/GPIO59)
unnamed: C5.2, R2.2
unnamed: C16.2, R13.2
unnamed: D7.2 (A), L2.2, U1.4 (SW)
unnamed: C3.1, C4.1, D7.1 (K), L1.1, R4.2
unnamed: C24.1, C25.1, C26.1, C27.1, D10.2 (A), L6.1, R13.1, R15.1, U6.8 (OUT)
unnamed: D10.1 (K), L7.2, U6.6 (SW)
unnamed: D11.2 (A), L8.2, U7.1 (SW)
unnamed: D14.2 (A), D15.2 (A), R11.2
unnamed: D14.1 (K), U5.7 (~CHRG)
unnamed: D15.1 (K), U5.6 (~DONE)
unnamed: F3.1, J6.A4 (VBUS), J6.A9 (VBUS), J6.B4 (VBUS), J6.B9 (VBUS)
unnamed: F1.2, J1.1 (Pin_1_1)
unnamed: F2.2, J2.1 (Pin_1_1)
unnamed: J6.A5 (CC1), R33.1
unnamed: J6.B5 (CC2), R29.1
unnamed: C5.1, U1.2 (COMP)
unnamed: C7.1, L2.1, L3.2, U1.5 (CTRL), U1.6 (VIN)
unnamed: R4.1, R6.2, U1.1 (FB)
unnamed: R10.2, SW1.2 (B), U2.5 (EN)
unnamed: R7.2, R8.1, U2.4 (FB)
unnamed: L4.2, U2.2 (SW)
unnamed: TP3.1 (1_1), U3.45 (GPIO36*)
unnamed: TP2.1 (1_1), U3.41 (USB_DM)
unnamed: TP1.1 (1_1), U3.40 (USB_DP)
unnamed: R14.2, U5.2 (ISET)
unnamed: C17.1, U6.1 (COMP)
unnamed: C23.2, R18.1, U6.3 (VIN), U6.4 (EN)
unnamed: C16.1, R12.1, R15.2, U6.9 (FB)
unnamed: C28.1, L5.2, R18.2, U6.5 (IN)
unnamed: C15.2, R12.2, U6.10 (VREF)
unnamed: R16.1, R17.1, U7.3 (FB)
unnamed: NT1.2, U8.6 (CSp)
unnamed: C32.2, U8.7 (REG)
V-USB: D9.1 (A), D9.2 (A), F3.2, Q1.4 (G), R9.1, R11.1, U5.4 (VIN)
Vbatt: C12.1, C22.1, C31.2, F1.1, F2.1, Q1.5 (D), Q1.6 (D), Q1.7 (D), Q1.8 (D), U5.5 (BAT), U5.8 (FB), U8.10 (BATT)

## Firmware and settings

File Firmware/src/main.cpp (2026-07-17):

#include <Arduino.h>
#include <string.h>
#include "Config.h"
#include "Console.h"
#include <WiFi.h>
#include "MyWifi.h"
#include "s3.h"
#include "Cellular.h"
#include "Batt.h"
#include "adc_cali_schemes.h"

// LVGL specific
#include "lvgl.h"
#define  LV_CONF_INCLUDE_SIMPLE
#include "Lvgl_code.h"
#include "demos/lv_demos.h"


// Hardware-specific library for the TFT screen
#include <SPI.h>
#include <TFT_eSPI.h> 
TFT_eSPI tft = TFT_eSPI();       // Invoke custom library

static lv_disp_t * disp;
static lv_indev_t * indev; // LVGL input device handle
static lv_color_t *buf1 = nullptr;
static lv_color_t *buf2 = nullptr;

//#define LV_USE_DRAW_SW 1
//#define LV_DRAW_SW_COMPLEX 1



/********************* Console **************************************/
// Handlers simples
extern console_t console[13];
void handler_help(char *)      { console_displayHelp(console); }
void handler_history(char *)   { console_displayHistory(); }
void handler_colors(char *)    { console_test();}
void handler_restart(char *)   { ESP.restart();}
void handler_detail(char *)    { ESP32_detail();}
void handler_temp(char *)      { Serial.printf("Internal Temperature: %.1fC\r\n",temperatureRead());}
//void handler_batt(char *)      { Serial.printf("Battery Voltage: %.1fV\r\n",battRead());}
void handler_wifi(char *)      { MyWifiScan();}
void handler_crash(char *)     { ESP32_crash();}
void handler_heap(char *)      { Serial.printf("Available heap: %u Bytes\r\n",ESP.getFreeHeap());}
void handler_version(char *)   { ESP32_version();}
void handler_lvgVersion(char *)  { Serial.printf("LVGL version %d.%d.%d\r\n",lv_version_major(), lv_version_minor(), lv_version_patch());}
void handler_touch(char *)     { touch_calibrate();}


console_t console[] = {
  {"help",       "Display this menu",                              0, handler_help},
  {"h",          "Display command history",                        0, handler_history},
  {"colors",     "Test the color in the AINSI console",            0, handler_colors},
  {"restart",    "Restart the ESP32-WROOM-32E-N8R2",               0, handler_restart},
  {"detail",     "give detail about the ESP32-S3 uCtrl used",      0, handler_detail},
  {"temp",       "give the internal temperature of the ESP32",     0, handler_temp},
  //{"batt",      "give the voltage of the battery",               0, handler_batt},
  {"wifi",       "scan all wifi SSID and give the strengh of the signal",  0, handler_wifi},
  {"crash",      "List the cause of the last reset",               0, handler_crash},
  {"heap",       "Return the remaining heap",                      0, handler_heap},
  {"version",    "Return the version of ESP_Arduino used",         0, handler_version},
  {"lvglVersion","Return the version of the LVGL library",         0, handler_lvgVersion},
  {"calTouch",   "Calibrate the touch screen",                     0, handler_touch},
  {nullptr, nullptr, 0, nullptr} // Sentinelle
};

//********************************************* */

Command console_cmd = CMD_noCommand;
String Input;
String *ptr;


void setup() {
  Serial.begin(115200);
  while(!Serial){
    vTaskDelay(100/portTICK_RATE_MS);
  }
  console_displayIntro();
  ptr = &Input;

  printf("\r\n> ");

  //*************************
  // Set up the display
  ScreenInit();

  //Use the touch calibration routine to get the correct values for your screen
  uint16_t calData[5] = { 288, 3622, 220, 3652, 5 }; 
  tft.setTouch((uint16_t *)calData);

  //*********************************
  // Initialize LVGL
  // 1. Calculate buffer size in pixels and bytes
  uint32_t buf_pixel_count = SCREEN_WIDTH * (SCREEN_HEIGHT / 10);
  uint32_t buf_byte_size = buf_pixel_count * sizeof(lv_color_t);

  // 2. Allocate dynamically from fast internal DMA memory
  //buf1 = (lv_color_t *)heap_caps_malloc(buf_byte_size, MALLOC_CAP_DMA | MALLOC_CAP_INTERNAL);
  //buf2 = (lv_color_t *)heap_caps_malloc(buf_byte_size, MALLOC_CAP_DMA | MALLOC_CAP_INTERNAL);

  //No real speed difference between malloc and aligned_alloc, but aligned_alloc is more explicit about the alignment requirement for DMA.
  buf1 = (lv_color_t *)heap_caps_aligned_alloc(32,buf_byte_size, MALLOC_CAP_DMA | MALLOC_CAP_INTERNAL);
  buf2 = (lv_color_t *)heap_caps_aligned_alloc(32,buf_byte_size, MALLOC_CAP_DMA | MALLOC_CAP_INTERNAL);


  // 3. Fallback check to ensure allocation succeeded
  if (buf1 == nullptr || buf2 == nullptr) {
      Serial.println("Critical Error: DMA Buffer allocation failed!");
      while(1) { vTaskDelay(1000 / portTICK_RATE_MS); }
  }

  lv_init();

  lv_tick_set_cb(my_tick);
  
  // Create display 
  disp = lv_display_create(SCREEN_WIDTH, SCREEN_HEIGHT); 
  lv_display_set_flush_cb(disp, my_flush_cb);
  
  // Change sizeof(buf1) to buf_byte_size
  lv_display_set_buffers(disp, buf1, buf2, buf_byte_size, LV_DISPLAY_RENDER_MODE_PARTIAL);

  // Setup Touch Input
  indev = lv_indev_create();
  lv_indev_set_type(indev, LV_INDEV_TYPE_POINTER);
  lv_indev_set_read_cb(indev, my_touchpad_read);

  //create_test_ui();
  lv_demo_benchmark(); 

  //**************************

  // Set 12-bit resolution (0-4095)
  analogSetWidth(12);
  // Set ADC attenuation to 6 dB (optimal for ~1.25V - 1.85V input)
  analogSetPinAttenuation(39, ADC_6db);

}

void loop() 
{
  /*char buffer[10];
  float VBatt, ChargeBatt;
  VBatt = (float)(analogReadMilliVolts(BattPin) * 2.0 * CALIBRATION_FACTOR / 1000.0);
  ChargeBatt = getBatteryPercentage(VBatt);
  sprintf(buffer, "Batt: %.2fV - %.0f%%",VBatt,ChargeBatt);
  game(buffer);*/

  // Let the GUI do its work
  lv_timer_handler(); 

  //vTaskDelay(5/portTICK_RATE_MS);
  
  int Input_char;
  char argument[10];
  int idx;

  // On récupère le caractère de l'UART
  Input_char = Serial.read();
  if (Input_char != -1) {
      console_cmd = console_getInput((uint8_t)Input_char, argument, console, &idx);

      // Si le parser a trouvé un index valide
      if (idx >= 0) {
          if (console[idx].func != NULL) {
              console[idx].func(argument);
          }
          Serial.printf("\r\n> ");
      } 
      else if (console_cmd == Error) {
          Serial.printf("Unknown command!\r\n> ");
      }
  }

}
  

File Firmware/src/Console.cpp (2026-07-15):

#include "Console.h"
#include <string.h>
#include <stdio.h>
#include <stdlib.h>
#include "Config.h"
#include <Arduino.h>


//Good article on escape character in AINSI:
// https://medium.com/@fulton_shaun/brighten-up-your-terminal-with-ansi-codes-cb5f5d2ff085 

#define CHAR_LENGTH 20
#define HISTORY_LENGTH 10

static char readString[CHAR_LENGTH];
static char History[HISTORY_LENGTH][CHAR_LENGTH];

// Variable globale pour mémoriser quelle commande exécuter
int last_cmd_index = -1;

command_t console_getInput(char input_char, char * argument, const console_t * console, int * cmd_index)
{
    static int8_t HistoryCounter = FIRST_TIME;
    int posy;
    
    command_t cmd = CMD_noCommand;
    * cmd_index = -1; // Reset à chaque appel

    //we read the first character
    //char input_char = uart_read(UART_CONSOLE);

    switch ((uint8_t)input_char)
    {
      case 13: 
      {//Si on appui sur "enter"
        //On veut que la dernière commande soit à la posion 0
        //Donc on décale tout le monde 1
        for (int i = (HISTORY_LENGTH - 1); i > 0; i--){
          strcpy(History[i],History[i-1]);
        }

        //On met la nouvelle valeur dans history
        strcpy(History[0],readString);

        //On imprime sur le port série 1 retour de ligne
        Serial.printf("\r\n");

        //*************  New parser   ***************
        // On cherche l'index de la commande dans le tableau
        * cmd_index = -1;
        
        // Séparation argument simple (cherche l'espace)
        char temp_read[50];
        strcpy(temp_read, readString);
        char *space_ptr = strchr(temp_read, ' ');

        if (space_ptr != NULL) {
            *space_ptr = '\0';
            strcpy(argument, space_ptr + 1);
        } else {
            strcpy(argument, "");
        }

        // Parcours du tableau pour trouver la fonction
        for (int i = 0; console[i].parser != NULL; i++) {
            if (strcmp(temp_read, console[i].parser) == 0) 
            {
                * cmd_index = i;
                cmd = CMD_noCommand; //
                break;
            }
        }
        
        if(* cmd_index == -1){ cmd = Error;} // Non trouvé
        
        //***************************************

        strcpy(readString,"");
        //Le seul moment où l'on ne remet pas le historycounter à FIRSTTIME
        // c'est si on a appuyé sur une flèche
        HistoryCounter = FIRST_TIME;
      break;
      }

      case 8: //Si on fait un backspace
        Serial.printf("\b \b");
        //on elève un caractère de readString
        if (strlen(readString) > 0) readString[strlen(readString)-1] = '\0';
        cmd = CMD_noCommand;
        //Le seul moment où l'on ne remet pas le historycounter à 0
        // c'est si on a appuyé sur une flèche
        HistoryCounter = FIRST_TIME;
      break;

      case 10:
        cmd = CMD_noCommand;
      break;

      case 27: //an arrow!!  we need to handle 3 caracters
        //On attends un peu pour être sur à 100% que les autres caractères ont eu le temps de rentrer dans le buffer
        delay(1);
        //Si ce n'est pas un '['
        if ((uint8_t)Serial.read()!=91){
            Serial.flush();
            cmd = Error;
            break;
        }
        //Si le 3e caractère est un 'A' c'est que c'est la flèche du haut, 'B' par en bas
        switch (Serial.read())
        {
            case 65:
              //Serial.println("flèche up!!");
              if (HistoryCounter == FIRST_TIME){
                HistoryCounter = 0;
              }
              else if (HistoryCounter <= 8){
                HistoryCounter++;
              }
              Serial.printf("\x1b[2K\r> ");
              Serial.printf(BGRN "%s" AINSIrst,History[HistoryCounter]);
              strcpy(readString,History[HistoryCounter]);
              cmd = CMD_noCommand;
            break;

            case 66:
              //Serial.println("flèche Down!!");
              if (HistoryCounter == FIRST_TIME){
                HistoryCounter = 0;
              }
              else if (HistoryCounter >= 1){
                HistoryCounter--;
              }
              Serial.printf("\x1b[2K\r> ");
              Serial.printf(BGRN "%s" AINSIrst,History[HistoryCounter]);
              strcpy(readString,History[HistoryCounter]);
              cmd = CMD_noCommand;
            break;

            default:
              cmd = Error;
            break;
        }

      break;

      case 32 ... 127:  //les caractère standard
        //Add to string
        posy = strlen(readString); 
        readString[posy] = input_char;
        readString[posy + 1] = '\0';
  
        //Echo

        //uart_write(USART_SERIAL, c);
        Serial.printf(BGRN "%c" AINSIrst,input_char);
               
        //Le seul moment où l'on ne remet pas le historycounter à 0
        // c'est si on a appuyé sur une flèche
        HistoryCounter = FIRST_TIME;
        cmd = CMD_noCommand;
      break;

      default:
        //Le seul moment où l'on ne remet pas le historycounter à 0
        // c'est si on a appuyé sur une flèche
        HistoryCounter = FIRST_TIME;
        cmd = Error;
      break;
    }
    //On vide le buffer d'entrée au ca où il y aurait encore dequoi dedans
    //fflush(stdin);
    //uart_empty_rx_buf();

    return cmd;
}



static void print_colored_stars(int count) {
    for (int i = 0; i < count; i++) {
        // Obtenir un index de couleur dynamique dans le cube de couleur RGB (16 à 231)
        // console_random() renvoie un int32_t (peut être négatif), 
        // donc on utilise abs() pour garantir un index positif avant le modulo.
        int color_index = (abs(console_random()) % 216) + 16; 
        
        // Séquence d'échappement ANSI étendue pour le texte (38;5;<index>)
        Serial.printf("\033[38;5;%dm*", color_index);
    }
    Serial.printf(AINSIrst); // "\033[0m" Réinitialise la couleur à blanc à la fin de la ligne
}

void console_displayHistory(){
    print_colored_stars(5);
    Serial.printf(" History: ");
    print_colored_stars(5);
    Serial.printf("\r\n");

    for (int i = 0; i < 10; i++){
        if(strlen(History[i]) == 0)
          {break;}
        Serial.printf("%s",History[i]);
        Serial.printf("\r\n");
    }
    Serial.printf("\r\n");
}

void console_displayIntro(){
  Serial.printf("\033[2J\033[H"); //clear the screen and put to cursor at home
  print_colored_stars(57); Serial.printf("\r\n");
  Serial.printf(    "   Use Tera Term in ANSI mode to support up/down arrows \r\n");
  Serial.printf(    "           Look nice with Consolas Font in 14           \r\n");
  Serial.printf(    "        Type 'help' to display all the commands         \r\n");
  Serial.printf(  "                  ESP32-WROOM-32E-N8R2                    \r\n");
  print_colored_stars(57); Serial.printf("\r\n> ");
}
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

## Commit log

2026-06-22 First commit.
    [BOM-esp32bb.csv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]
2026-06-22 Clean up
    [power.kicad_sch, power_analog.kicad_sch]
2026-06-22 Good ESP32 base project
2026-06-22 Clean-up du projet pour qu'il fonctionne sur le ESP32 (et non le ESP32-S3)
2026-06-22 Add image of ESP32 BaseBoard to README
2026-06-24 Adding WRK-GBR and Design
    [Batt-Screen.xlsx]
2026-07-03 TFT_eSPI correctly installed USer_Setup.h is probably not called. Need to fix
    [main.cpp]
2026-07-07 restore power sheet in schematic
    [power.kicad_sch]
2026-07-08 Game Of life and Batt voltage
2026-07-10 Kicad have to much fun
2026-07-15 ADC cal, BATT and rev-up update
2026-07-17 Touch calibration
2026-09-01 kicad stuff
    [esp32bb.kicad_pcb]
2026-09-28 New BaseBoard
    [1040310811.stp, BOM-esp32bb.csv, esp32-V2.kicad_pcb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]
2026-09-28 Deleting old files
    [esp32bb.kicad_pcb]
2026-09-28 S31 fully connected
    [Pinout-screen.xlsx, esp32-V2.kicad_sch, powersource.kicad_sch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]
2026-10-01 Schematic Done
    [esp32-V2.kicad_pcb, esp32-V2.kicad_sch, esp32-V2.xlsx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]
2026-10-02 Flip the connector and Pot in the layout
    [esp32-V2.kicad_pcb, esp32-V2.step]
2026-10-02 Adding .step to connectors and S31
    [esp32-V2.kicad_pcb]
2026-10-07 Layout: unrouted = 0
    [esp32-V2.kicad_pcb, esp32-V2.kicad_sch, powersource.kicad_sch]
2026-10-08 Layout cleaned
    [esp32-V2.kicad_pcb, esp32-V2.kicad_sch, power.kicad_sch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]
2026-10-09 Update de la librairy et du BOM
    [BaseBoard-R200.xlsx, esp32-V2.csv, esp32-V2.kicad_pcb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]
2026-10-15 Gerbers Generation
